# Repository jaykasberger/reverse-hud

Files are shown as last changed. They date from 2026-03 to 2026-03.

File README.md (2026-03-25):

# Reverse HUD
Design files and code for the Reverse HUD.  https://jaykasberger.com/projects/reverse-hud/

This device provides a transparent heads-up display, though it doesn't include the necessary optics
for use as an actual first-person HUD - it's more of a fun costume piece, and/or a way to display
information to the people around you.

## Safety Note and Disclaimer

These files and instructions are for demonstration only.  **Build and use this at your own risk.** 
Operating any kind of equipment close to your eye is inherently dangerous.

## Bill of Materials

- Waveshare transparent OLED display component: https://www.waveshare.com/1.51inch-transparent-oled.htm
- Seeed Studio XIAO MG24 Sense: https://www.seeedstudio.com/Seeed-XIAO-MG24-Sense-p-6248.html  _(Note: you will need one with pre-soldered headers, or you can add them yourself)_
- M3 socket cap screws (3)
- M3 heat-set inserts (3)
- USB-C cable
- USB charging battery

## Build Instructions

- Print the enclosure STLs using the 3D printer of your choice.  I recommend transparent PCTG or PETG.
- Using a soldering iron and the proper attachment, secure the heat-set inserts into the matching holes in the shroud.
- Fit the OLED display screen into the screen area of the frame, making sure the display faces outwards (see photo).
- Run the ribbon cable through the curved guide.  Snap the controller board in place - the pegs in the enclosure will friction-fit with the mounting 
holes in the board, but you can melt the pegs a little to permanently secure the board if needed.
- Snap the screen retainer in place behind the display screen.
- Run the wires from the Waveshare board through the large hole in the enclosure.
- Plug the MG24's headers into the matching holes in the enclosure so that the USB connector is facing away from the display screen.
- Connect the wires from the Waveshare to the MG24 as follows:
- - VCC -> 3V3
- - GND -> GND
- - DIN -> D10
- - CLK -> D8 
- - CS  -> D1
- - DC  -> D3
- - RST -> D2
- Slide the cover over the enclosure.
- Attach the unit to the left temple of a pair of glasses and use the socket cap screws to secure it in place.  You might not need (or be able to use) all three screws.
- Use the Arduino toolchain or IDE to load hud_multimode.ino onto the Seeed board.  You may want to edit it first to provide your own URL for the QR code.  Also, you may have to load the board specification from Seeed, as well as several libraries including ArduinoFFT.
- Plug in the USB battery, and you're running.

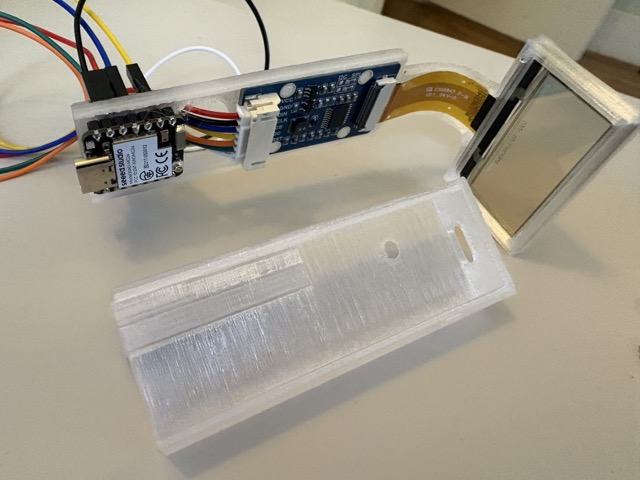
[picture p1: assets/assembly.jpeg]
Assembly


## Usage

Pretty simple - just tilt your head to the side to switch modes.  
The modes available are:

- Starfield animation
- Artificial horizon
- Real-time audio spectrogram
- QR code (for your LinkedIn, website, etc.)
- Simultaneous time on Earth and Mars (note: this device doesn't set the time from NTP, so it won't be accurate)

There's an easter egg in the "starfield" display; try whistling the first three notes of the "Star Trek" intro music.

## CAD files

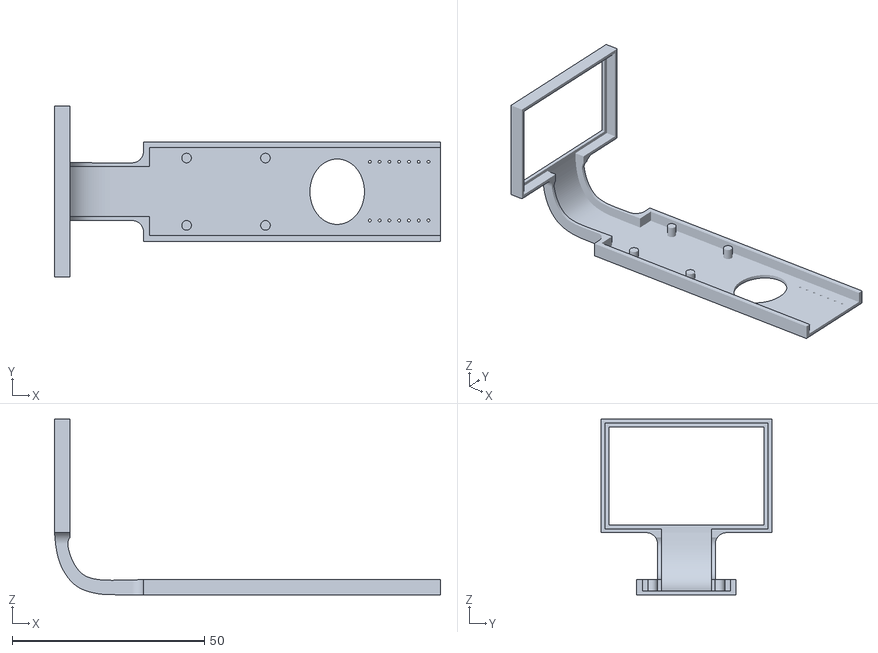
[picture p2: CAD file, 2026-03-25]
stl/frame.stl
100.3 x 44.3 x 45.7

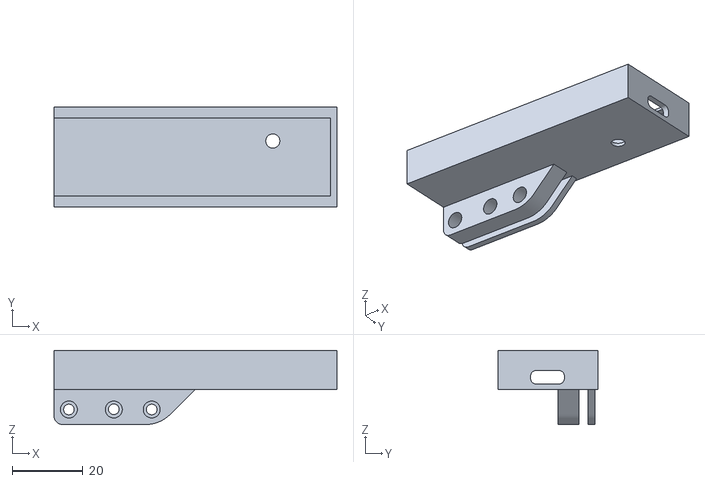
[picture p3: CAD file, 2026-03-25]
stl/shroud.stl
80.1 x 28.2 x 21.0

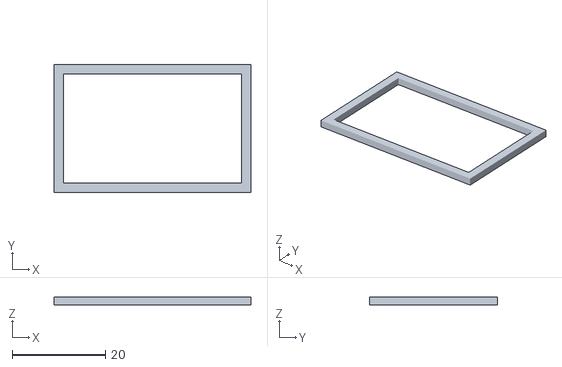
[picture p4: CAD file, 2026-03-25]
stl/screen_retainer.stl
42.3 x 27.5 x 1.66

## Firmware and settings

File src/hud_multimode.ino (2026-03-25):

/*
 * HUD Eyepiece — Multi-Mode Display with IMU Gesture Switching
 * XIAO MG24 Sense + Waveshare 1.51" Transparent OLED (SSD1309)
 *
 * Display modes cycle on a sharp head jerk (detected via gyroscope).
 * Current modes:
 *   0 — Starfield
 *   1 — FFT Spectrogram (frequency histogram)
 *   2 — IMU Horizon (pitch/roll artificial horizon)
 *   3 — Splash / info screen
 *
 * Wiring:
 *   VCC  -> 3V3      GND  -> GND
 *   DIN  -> D10       CLK  -> D8
 *   CS   -> D1        DC   -> D2        RST  -> D3
 *
 * Libraries:
 *   - U8g2            (olikraus)
 *   - arduinoFFT      (kosme)
 *   - Seeed_Arduino_LSM6DS3
 */

#include <U8g2lib.h>
#include <SPI.h>
#include <Wire.h>
#include <LSM6DS3.h>
#include <arduinoFFT.h>
#include <qrcode.h>

struct Star {
    float x, y, z;
};

// =============================================================
//  Hardware setup
// =============================================================

// Display — SSD1309 128x64 HW SPI
U8G2_SSD1309_128X64_NONAME0_F_4W_HW_SPI u8g2(
    U8G2_MIRROR, /* cs=*/ D1, /* dc=*/ D2, /* rst=*/ D3
);

// IMU — LSM6DS3TR-C on I2C
LSM6DS3 imu(I2C_MODE, 0x6A);

// Microphone
#define MIC_PWR_PIN   PC8
#define MIC_ADC_PIN   PC9



// =============================================================
//  Mode management
// =============================================================

#define NUM_MODES  5
int currentMode = 0;

// Forward declarations for mode functions
void mode_starfield_init();
void mode_starfield_draw();
void mode_spectrogram_init();
void mode_spectrogram_draw();
void mode_horizon_init();
void mode_horizon_draw();
void mode_splash_init();
void mode_splash_draw();

typedef void (*ModeInitFn)();
typedef void (*ModeDrawFn)();

struct DisplayMode {
    const char* name;
    ModeInitFn  init;
    ModeDrawFn  draw;
};

void mode_clock_init();
void mode_clock_draw();

DisplayMode modes[NUM_MODES] = {
    { "STARFIELD",    mode_starfield_init,    mode_starfield_draw    },
    { "SPECTROGRAM",  mode_spectrogram_init,  mode_spectrogram_draw  },
    { "HORIZON",      mode_horizon_init,      mode_horizon_draw      },
    { "LINKEDIN",     mode_splash_init,       mode_splash_draw       },
    { "EARTH/MARS",   mode_clock_init,        mode_clock_draw        },
};



// =============================================================
//  MODE — Earth / Mars Clock (portrait orientation)
// =============================================================

// Set this to the current Unix timestamp (UTC) just before uploading.
// Get it from epochconverter.com
#define BOOT_UTC_EPOCH  1773541800UL

unsigned long bootMillis = 0;

void mode_clock_init() {
    bootMillis = millis();
}

void mode_clock_draw() {
    // Current UTC as Unix timestamp
    unsigned long elapsed = (millis() - bootMillis) / 1000UL;
    unsigned long utcNow = BOOT_UTC_EPOCH + elapsed;

    // --- Earth time (UTC) ---
    // unsigned long daySeconds = utcNow % 86400UL;
    // int eHour = daySeconds / 3600;
    // int eMin  = (daySeconds % 3600) / 60;
    // int eSec  = daySeconds % 60;

    // PDT = UTC - 7
    unsigned long daySeconds = utcNow % 86400UL;
    int localSeconds = (int)(daySeconds) - (7 * 3600);
    if (localSeconds < 0) localSeconds += 86400;
    int eHour = localSeconds / 3600;
    int eMin  = (localSeconds % 3600) / 60;
    int eSec  = localSeconds % 60;

    // --- Mars time (MTC) ---
    // Julian Date from Unix time
    double jd = ((double)utcNow / 86400.0) + 2440587.5;

    // Mars Sol Date
    double msd = (jd - 2405522.0028779) / 1.0274912517;

    // Mars Coordinated Time = fractional sol * 24 hours
    double mtcFrac = fmod(msd, 1.0);
    if (mtcFrac < 0.0) mtcFrac += 1.0;
    double mtcTotalSec = mtcFrac * 86400.0;  // Mars "seconds" in a sol
    int mHour = (int)(mtcTotalSec / 3600.0) % 24;
    int mMin  = (int)(fmod(mtcTotalSec, 3600.0) / 60.0);
    int mSec  = (int)(fmod(mtcTotalSec, 60.0));

    // Current sol number (for display)
    unsigned long solNumber = (unsigned long)msd;

    // --- Draw in portrait ---
    // Buffer X (0..127) = physical vertical, low X = bottom
    // Buffer Y (0..63) = physical horizontal
    // All text uses setFontDirection(1) for portrait reading

    u8g2.clearBuffer();
    u8g2.setFontDirection(1);

    char buf[24];

    // Earth section — upper portion of physical display (high buffer X)
    u8g2.setFont(u8g2_font_5x7_tr);
    const char* earthLabel = "EARTH PDT";
    int tw = u8g2.getStrWidth(earthLabel);
    u8g2.drawStr(90, (64 - tw) / 2, earthLabel);

    u8g2.setFont(u8g2_font_7x14B_tr);
    snprintf(buf, sizeof(buf), "%02d:%02d:%02d", eHour, eMin, eSec);
    tw = u8g2.getStrWidth(buf);
    u8g2.drawStr(75, (64 - tw) / 2, buf);

    // Divider line across physical width at midpoint
    u8g2.setFontDirection(0);  // temporarily reset for line drawing
    u8g2.drawVLine(64, 0, 64);
    u8g2.setFontDirection(1);

    // Mars section — lower portion (low buffer X)
    u8g2.setFont(u8g2_font_5x7_tr);
    snprintf(buf, sizeof(buf), "SOL %lu", solNumber);
    tw = u8g2.getStrWidth(buf);
    u8g2.drawStr(52, (64 - tw) / 2, buf);

    u8g2.setFont(u8g2_font_7x14B_tr);
    snprintf(buf, sizeof(buf), "%02d:%02d:%02d", mHour, mMin, mSec);
    tw = u8g2.getStrWidth(buf);
    u8g2.drawStr(37, (64 - tw) / 2, buf);

    // Small label at physical bottom
    u8g2.setFont(u8g2_font_4x6_tr);
    const char* mtcLabel = "MTC";
    tw = u8g2.getStrWidth(mtcLabel);
    u8g2.drawStr(28, (64 - tw) / 2, mtcLabel);

    u8g2.setFontDirection(0);  // reset for other modes
    u8g2.sendBuffer();
}

// =============================================================
//  Gesture detection (gyroscope-based)
// =============================================================

// We detect a sharp YAW (rotation around Z axis) as the switch gesture.
// This corresponds to a quick horizontal head turn.
// Threshold in degrees/second — tune to your preference.
#define GESTURE_GYRO_THRESHOLD  200.0f   // dps — how hard you need to jerk
#define GESTURE_COOLDOWN_MS     800      // ignore gestures for this long after one fires

unsigned long lastGestureTime = 0;

bool detectGesture() {
    float gz = imu.readFloatGyroX();

    // Check for sharp yaw in either direction
    if (fabs(gz) > GESTURE_GYRO_THRESHOLD) {
        unsigned long now = millis();
        if ((now - lastGestureTime) > GESTURE_COOLDOWN_MS) {
            lastGestureTime = now;
            return true;
        }
    }
    return false;
}

void switchMode() {
    currentMode = (currentMode + 1) % NUM_MODES;
    modes[currentMode].init();

    // Brief flash: show mode name for ~400ms
    u8g2.clearBuffer();
    /*
    u8g2.setFont(u8g2_font_7x14B_tr);
    int tw = u8g2.getStrWidth(modes[currentMode].name);
    u8g2.drawStr((128 - tw) / 2, 38, modes[currentMode].name);
    u8g2.sendBuffer();
    delay(400);
    */
    u8g2.sendBuffer();
}



// =============================================================
//  MODE 1 — FFT Spectrogram (frequency histogram)
// =============================================================

#define FFT_SAMPLES       256
#define FFT_SAMPLING_FREQ 8000
#define FFT_NUM_BARS      64
#define FFT_BAR_MAX_H      31
#define NOISE_FLOOR_DB     50.0
#define DYNAMIC_RANGE_DB   30.0
#define DECAY_FACTOR        0.25f


float vReal[FFT_SAMPLES];
float vImag[FFT_SAMPLES];
ArduinoFFT<float> FFT(vReal, vImag, FFT_SAMPLES, FFT_SAMPLING_FREQ);
float displayBars[FFT_NUM_BARS];


// State


// =============================================================
//  Whistle detector — simple 3-note sequence
// =============================================================

#define WHISTLE_MIN_MAG      8.0f
#define WHISTLE_SEMI_TOLERANCE  2    // +/- semitones for fuzz
#define WHISTLE_HOLD_MS      1000    // each note must sustain this long
#define WHISTLE_TIMEOUT_MS   4000    // reset if gap between notes too long
#define WHISTLE_MIN_FREQ   400.0f
#define WHISTLE_MAX_FREQ   2500.0f

const int targetNotes[] = { 90, 85, 88 };
#define TARGET_LEN  3

int   matchIndex = 0;              // which note we're waiting for next
unsigned long noteStartTime = 0;   // when current note started being heard
unsigned long lastHeardTime = 0;   // last frame we heard the target note
bool  trekTriggered = false;

int currentDetectedSemi = -1;

void resetTrekDetector() {
    matchIndex = 0;
    noteStartTime = 0;
    lastHeardTime = 0;
    trekTriggered = false;
    currentDetectedSemi = -1;
}

// Convert frequency to semitone number (A4=440Hz = semitone 69)
int freqToSemitone(float freq) {
    return (int)(12.0f * log2f(freq / 440.0f) + 69.0f + 0.5f);
}

// Find dominant tonal frequency from current FFT data
float findWhistlePitch() {
    int minBin = (int)(WHISTLE_MIN_FREQ / ((float)FFT_SAMPLING_FREQ / FFT_SAMPLES)) + 1;
    int maxBin = (int)(WHISTLE_MAX_FREQ / ((float)FFT_SAMPLING_FREQ / FFT_SAMPLES));
    if (maxBin >= FFT_SAMPLES / 2) maxBin = FFT_SAMPLES / 2 - 1;

    double peakMag = 0;
    int peakBin = 0;
    for (int i = minBin; i <= maxBin; i++) {
        if (vReal[i] > peakMag) {
            peakMag = vReal[i];
            peakBin = i;
        }
    }

    // Check magnitude is above noise
    double dB = (peakMag > 1.0) ? 20.0 * log10(peakMag) : 0.0;
    if (dB < WHISTLE_MIN_MAG + NOISE_FLOOR_DB) return 0.0f;

    // Check it's tonal — peak should dominate its neighbors
    double neighborAvg = 0;
    int count = 0;
    for (int i = peakBin - 3; i <= peakBin + 3; i++) {
        if (i >= minBin && i <= maxBin && i != peakBin) {
            neighborAvg += vReal[i];
            count++;
        }
    }
    if (count > 0) neighborAvg /= count;
    if (peakMag < neighborAvg * 3.0) return 0.0f;

    // Parabolic interpolation for sub-bin accuracy
    double alpha = (peakBin > 0) ? vReal[peakBin - 1] : 0;
    double beta  = vReal[peakBin];
    double gamma = (peakBin < FFT_SAMPLES / 2 - 1) ? vReal[peakBin + 1] : 0;
    double correction = 0.0;
    if (alpha + gamma > 0) {
        correction = 0.5 * (alpha - gamma) / (alpha - 2.0 * beta + gamma);
    }
    float refinedBin = (float)peakBin + (float)correction;

    return refinedBin * (float)FFT_SAMPLING_FREQ / FFT_SAMPLES;
}

bool checkForTrekWhistle() {
    if (trekTriggered) return false;

    unsigned long now = millis();

    // Timeout — reset if too long since we last heard the right note
    if (matchIndex > 0 && (now - lastHeardTime) > WHISTLE_TIMEOUT_MS) {
        Serial.println(">> Timeout, resetting.");
        matchIndex = 0;
    }

    float freq = findWhistlePitch();
    if (freq < 1.0f) return false;

    int semi = freqToSemitone(freq);
    int target = targetNotes[matchIndex];

    if (abs(semi - target) <= WHISTLE_SEMI_TOLERANCE) {
        // We're hearing the right note
        if (currentDetectedSemi != matchIndex) {
            // Just started hearing this target
            currentDetectedSemi = matchIndex;
            noteStartTime = now;
            Serial.print(">> Hearing note ");
            Serial.print(matchIndex);
            Serial.print(" (target=");
            Serial.print(target);
            Serial.print(" heard=");
            Serial.print(semi);
            Serial.println(")");
        }
        lastHeardTime = now;

        // Has it been held long enough?
        if ((now - noteStartTime) >= WHISTLE_HOLD_MS) {
            Serial.print(">> Note ");
            Serial.print(matchIndex);
            Serial.println(" CONFIRMED");
            matchIndex++;
            currentDetectedSemi = -1;

            if (matchIndex >= TARGET_LEN) {
                Serial.println("*** PATTERN MATCHED — ENGAGE! ***");
                trekTriggered = true;
                return true;
            }
        }
    } else {
        // Wrong note — but don't reset unless we've drifted far off
        // This allows sliding into a note
        if (currentDetectedSemi == matchIndex && abs(semi - target) > WHISTLE_SEMI_TOLERANCE + 2) {
            currentDetectedSemi = -1;
        }
    }

    return false;
}

// =============================================================
//  MODE 0 — Starfield with Warp Easter Egg
// =============================================================

#define NUM_STARS     64
#define MAX_DEPTH    256.0f
#define STAR_SPEED     4.0f

// Warp state
enum WarpState {
    WARP_IDLE,
    WARP_ACCELERATING,
    WARP_FLASH,
    WARP_COOLDOWN
};

WarpState warpState = WARP_IDLE;
unsigned long warpStartTime = 0;

#define WARP_ACCEL_DURATION_MS   2000   // ramp up over 2 seconds
#define WARP_FLASH_DURATION_MS    400   // white screen
#define WARP_COOLDOWN_DURATION_MS 500   // fade back to normal

Star stars[NUM_STARS];

// Store previous screen positions for trail drawing
int prevSX[NUM_STARS];
int prevSY[NUM_STARS];
bool hasPrev[NUM_STARS];

void initStar(Star &s, int idx) {
    s.x = (float)random(-128, 128);
    s.y = (float)random(-64, 64);
    s.z = (float)random(1, (int)MAX_DEPTH);
    hasPrev[idx] = false;
}

void mode_starfield_init() {
    for (int i = 0; i < NUM_STARS; i++) initStar(stars[i], i);
    warpState = WARP_IDLE;
    resetTrekDetector();
}

void triggerWarp() {
    warpState = WARP_ACCELERATING;
    warpStartTime = millis();
}

void mode_starfield_draw() {
    unsigned long now = millis();
    unsigned long elapsed = now - warpStartTime;

    // --- Warp state machine ---
    float speedMultiplier = 1.0f;
    float trailStrength = 0.0f;

    switch (warpState) {
        case WARP_IDLE:
            speedMultiplier = 1.0f;
            trailStrength = 0.0f;
            break;

        case WARP_ACCELERATING: {
            float t = (float)elapsed / WARP_ACCEL_DURATION_MS;
            if (t >= 1.0f) {
                warpState = WARP_FLASH;
                warpStartTime = now;
                break;
            }
            // Exponential ramp: 1x to ~20x
            speedMultiplier = 1.0f + 19.0f * t * t;
            // Trails fade in
            trailStrength = t;
            break;
        }

        case WARP_FLASH:
            if (elapsed > WARP_FLASH_DURATION_MS) {
                warpState = WARP_COOLDOWN;
                warpStartTime = now;
                // Reinit stars for clean return
                for (int i = 0; i < NUM_STARS; i++) initStar(stars[i], i);
            }
            // Full white screen
            u8g2.clearBuffer();
            for (int x = 0; x < 128; x++) {
                u8g2.drawVLine(x, 0, 64);
            }
            u8g2.sendBuffer();
            return;  // skip normal drawing

        case WARP_COOLDOWN:
            if (elapsed > WARP_COOLDOWN_DURATION_MS) {
                warpState = WARP_IDLE;
                resetTrekDetector();
            }
            // Fade from bright back to normal
            speedMultiplier = 1.0f;
            trailStrength = 0.0f;
            break;
    }

    // --- Run quick FFT for whistle detection (only when idle) ---
    static int fftSkipCounter = 0;
    if (warpState == WARP_IDLE && (++fftSkipCounter % 3 == 0)) {
        unsigned long periodUs = 1000000UL / FFT_SAMPLING_FREQ;
        double dcSum = 0.0;
        for (int i = 0; i < FFT_SAMPLES; i++) {
            unsigned long t0 = micros();
            vReal[i] = (double)analogRead(MIC_ADC_PIN);
            vImag[i] = 0.0;
            dcSum += vReal[i];
            while ((micros() - t0) < periodUs) {}
        }
        double dcOff = dcSum / FFT_SAMPLES;
        for (int i = 0; i < FFT_SAMPLES; i++) vReal[i] -= dcOff;

        FFT.windowing(FFT_WIN_TYP_HAMMING, FFT_FORWARD);
        FFT.compute(FFT_FORWARD);
        FFT.complexToMagnitude();

        if (checkForTrekWhistle()) {
            triggerWarp();
        }
    }

    // --- Draw starfield ---
    // During warp, don't fully clear — let old frames partially persist for trails
    if (trailStrength > 0.5f) {
        // Dim existing pixels by drawing semi-sparse black overlay
        // More trail = less clearing
        int clearDensity = (int)((1.0f - trailStrength) * 8) + 1;
        for (int x = 0; x < 128; x++) {
            for (int y = 0; y < 64; y++) {
                if ((x + y) % clearDensity == 0) {
                    u8g2.setDrawColor(0);
                    u8g2.drawPixel(x, y);
                    u8g2.setDrawColor(1);
                }
            }
        }
    } else {
        u8g2.clearBuffer();
    }

    float currentSpeed = STAR_SPEED * speedMultiplier;

    for (int i = 0; i < NUM_STARS; i++) {
        float oldZ = stars[i].z;

        stars[i].z -= currentSpeed;
        if (stars[i].z <= 0) {
            initStar(stars[i], i);
            stars[i].z = MAX_DEPTH;
            continue;
        }

        float invZ = 1.0f / stars[i].z;
        int sx = (int)(stars[i].x * (MAX_DEPTH * 0.5f) * invZ) + 64;
        int sy = (int)(stars[i].y * (MAX_DEPTH * 0.5f) * invZ) + 32;

        if (sx < 0 || sx >= 128 || sy < 0 || sy >= 64) {
            initStar(stars[i], i);
            continue;
        }

        float normZ = stars[i].z / MAX_DEPTH;

        if (trailStrength > 0.1f && hasPrev[i]) {
            // Draw streak from previous position to current
            u8g2.drawLine(prevSX[i], prevSY[i], sx, sy);
        } else {
            // Normal dot rendering
            if (normZ < 0.2f)       u8g2.drawBox(sx - 1, sy - 1, 3, 3);
            else if (normZ < 0.5f)  u8g2.drawBox(sx, sy, 2, 2);
            else                    u8g2.drawPixel(sx, sy);
        }

        prevSX[i] = sx;
        prevSY[i] = sy;
        hasPrev[i] = true;
    }

    u8g2.sendBuffer();
}

void mode_spectrogram_init() {
    memset(displayBars, 0, sizeof(displayBars));
}

void mode_spectrogram_draw() {
    // Sample audio
    unsigned long periodUs = 1000000UL / FFT_SAMPLING_FREQ;
    double dcSum = 0.0;
    for (int i = 0; i < FFT_SAMPLES; i++) {
        unsigned long t0 = micros();
        vReal[i] = (double)analogRead(MIC_ADC_PIN);
        vImag[i] = 0.0;
        dcSum += vReal[i];
        while ((micros() - t0) < periodUs) {}
    }

    // Remove DC offset
    double dcOff = dcSum / FFT_SAMPLES;
    for (int i = 0; i < FFT_SAMPLES; i++) vReal[i] -= dcOff;

    // FFT
    FFT.windowing(FFT_WIN_TYP_HAMMING, FFT_FORWARD);
    FFT.compute(FFT_FORWARD);
    FFT.complexToMagnitude();

    // Map to bars
    for (int i = 0; i < FFT_NUM_BARS; i++) {        
        double mag = vReal[i + 1];
        double dB = (mag > 1.0) ? 20.0 * log10(mag) : 0.0;
        dB -= NOISE_FLOOR_DB;
        if (dB < 0.0) dB = 0.0;
        float barH = (float)(dB / DYNAMIC_RANGE_DB) * FFT_BAR_MAX_H;
        if (barH > FFT_BAR_MAX_H) barH = FFT_BAR_MAX_H;

        if (barH >= displayBars[i]) displayBars[i] = barH;
        else displayBars[i] = displayBars[i] * DECAY_FACTOR + barH * (1.0f - DECAY_FACTOR);
    }

    // Draw
    u8g2.clearBuffer();
    for (int x = 0; x < FFT_NUM_BARS; x++) {
        int h = (int)(displayBars[x] + 0.5f);
        if (h > 0) {
            u8g2.drawVLine(63 + x, FFT_BAR_MAX_H - h + 1, h);
            u8g2.drawVLine(63 + x, FFT_BAR_MAX_H, h);
            u8g2.drawVLine(63 - x, FFT_BAR_MAX_H - h + 1, h);
            u8g2.drawVLine(63 - x, FFT_BAR_MAX_H, h);
        } 
        //u8g2.drawVLine(x, FFT_BAR_MAX_H - h + 1, h);
    }
    u8g2.drawHLine(0, FFT_BAR_MAX_H, 128);
    u8g2.sendBuffer();
}

// =============================================================
//  MODE 2 — Artificial Horizon (portrait, board rotated 90° CW)
// =============================================================

// When the board is mounted 90° clockwise (looking at the display):
//   Physical "up"      = board -X axis
//   Physical "right"   = board +Y axis
//   Physical "forward" = board +Z axis
//
// So we remap:
//   pitch = rotation around physical right axis = derived from board X & Z
//   roll  = rotation around physical forward axis = derived from board Y & Z

float smoothPitch = 0.0f;
float smoothRoll  = 0.0f;

float heading = 0.0f;           // relative heading in degrees, 0..360
unsigned long lastHeadingTime = 0;

#define HORIZON_ALPHA  0.15f

void mode_horizon_init() {
    smoothPitch = 0.0f;
    smoothRoll  = 0.0f;
    heading = 0.0f;
    lastHeadingTime = millis();
}

bool validate_coords(int x1, int x2, int y1, int y2) {
    if (x1 < 0) return false;
    if (x1 > 63) return false;
    if (x2 < 0) return false;
    if (x2 > 63) return false;
    if (y1 < 0) return false;
    if (y1 > 127) return false;
    if (y2 < 0) return false;
    if (y2 > 127) return false;
    return true;
}
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
void loop() {
    // Check for gesture (runs every frame, very fast)
    if (detectGesture()) {
        Serial.print("Gesture! Switching to mode ");
        switchMode();
        Serial.println(modes[currentMode].name);
    }

    // Draw current mode
    modes[currentMode].draw();
}
